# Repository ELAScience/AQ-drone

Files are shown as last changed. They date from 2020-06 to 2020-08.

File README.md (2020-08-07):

# AQ-drone

The AQ-drone project is an open source air quality measuring system utilizing drone technology to conduct air quality metrics. This project is inspired by the [JPL Open Source Rover Project](https://github.com/nasa-jpl/open-source-rover).

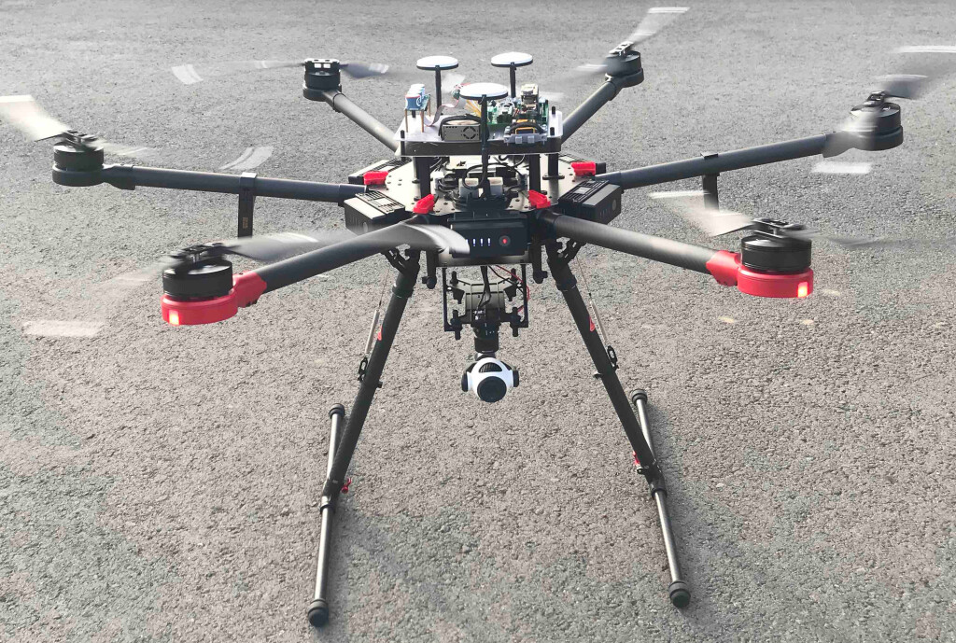
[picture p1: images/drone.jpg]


The goals of this project are two-fold:

1. To develop a pedagogical curriculum from which students can apply engineering and science skills to a real problem

2. To aggregate data from a distributed network of air quality sensors with the ultimate goal of understanding and improving environment impact of pollution on the community

## About AQ-drone

According to the EPA, air quality differs from region to region due to geographic location, proximity to pollution sources, and weather. Public health and environmental justice issues affect vulnerable communities, such as East Los Angeles, due to their proximity to freeways and interchanges, rail yards, industrial complexes and population density. Poor air quality is associated with detrimental effects on health and an increase in mortality (Dockery, et al., 1993). Establishing a cost effective and sustainable community driven air quality program is not only beneficial but necessary.

As community air quality investigators, we need to educate various stakeholders in the community about the air they experience in their surroundings. These units of concern are the residents, municipalities, elected officials, industrial/commercial businesses.

## Pedagogical Value

A key component of successful STEM instruction involves the application of concepts learned to real-world problems. Not only does this increase the retention of information and scientific inquiry, but, in the process, can lead to discoveries and contributions, thereby expanding the knowledge base as well as increasing the probability of pursuing a STEM-related career.

## Scientific Data

To test ambient air quality and pollution levels using aerial data collection rather than stationary, ground-level measuring locations.
The data collection should include metrics on carbon monoxide, ozone, nitrogen oxide, volatile organic compounds, particulate matter, hydrogen sulfide, methane and airborne lead.

## Equipment

The DJI Matrice 600 Pro Hexacopter drone is determined to be the most appropriate vehicle for carrying out this mission. Additionally, we will use on commercially available sensors for data collection. The sensors used and needed hardware can be found in the [hardware section](hardware/README.md). Post flight data analysis will be accomplished using open source software, and for campaign planning, we rely on Google Earth.

## Software

The software used can be found in the `software` directory. Documentation and instructions can be found in the [software guide](software/README.md).

## Project Team

### Principal Investigator

John J. Tran

### Development Team

Kevin Benavente, Steven Conaway, Michael Murray, and Jacqueline Curiel.

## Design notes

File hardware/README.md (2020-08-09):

# Hardware Guide

This project makes use of several off-the-shelf parts, however, it requires a few that are custom-made via PCB fabrication and 3D Printing.

## Parts List

| Name | Quantity | Cost (per unit, if applicable) | Supplier | Notes |
| --- | --- | --- | --- | --- |
| Custom Made PCB | 1 | \$0.40 | | We used JLCPCB to manufacture 5 copies for \$2.00 + shipping |
| PCB Base Plate | 1 | \$20.00 | | Used to secure the PCB and sensors to the drone's mounting kit. We used our own printer but makexyz.com seems to be the most cost-efficient. |
| Stacking Headers for Feather - 12-pin and 16-pin female headers | 3 | \$1.25 | Adafruit | Used to attach the FeatherWings to the Feather and the Feather to the PCB |
| Adafruit Feather M4 Express - Featuring ATSAMD51 - ATSAMD51 Cortex M4 | 1 | \$22.95 | Adafruit | |
| Adalogger FeatherWing - RTC + SD Add-on For All Feather Boards | 1 | \$8.95 | Adafruit | |
| Adafruit Ultimate GPS FeatherWing | 1 | \$39.95 | Adafruit | |
| GPS Antenna - External Active Antenna - 3-5V 28dB 5 Meter SMA | 1 | \$14.95 | Adafruit | |
| SMA to uFL/u.FL/IPX/IPEX RF Adapter Cable | 1 | \$3.95 | Adafruit | |
| CR1220 12mm Diameter - 3V Lithium Coin Cell Battery - CR1220 | 1 | \$0.95 | Adafruit | Backup battery for the GPS |
| ADS1115 16-Bit ADC - 4 Channel with Programmable Gain Amplifier | 2 | \$14.95 | Adafruit | |
| Adafruit BMP388 - Precision Barometric Pressure and Altimeter | 1 | \$9.95 | Adafruit | |
| Adafruit Sensirion SHT31-D - Temperature & Humidity Sensor | 1 | \$13.95 | Adafruit | |
| PM2.5 Air Quality Sensor and Breadboard Adapter Kit - PMS5003 | 1 | \$39.95 | Adafruit | |
| Arduino Nano | 1 | \$9.00 | Amazon | Used to interface with the PMS5003 |
| 3.3V, 3.6A Step-Down Voltage Regulator D36V28F3 | 1 | \$11.95 | Pololu | |
| 5V, 3.2A Step-Down Voltage Regulator D36V28F5 | 1 | \$11.95 | Pololu | |
| AlphaSense 4-Way AFE with CO, O3, NO, and H2S | 1 | \$379.00 | AlphaSense | |
| DJI Matrice 600 Pro | 1 | \$5699.00 | DJI | |
| DJI Matrice 600 Series Zenmuse X3/X5/XT/Z3 Series Gimbal Mounting Bracket | 1 | \$200.00 | DJI | |
| DJI Zenmuse X3 | 1 | - | DJI | At the time of making this list, pricing information for this was unavailable. |
| DJI Matrice 600 Upper Expansion Bay Kit | 1 | - | DJI | At the time of making this list, pricing information for this was unavailable. |
| - | - | - | - | - |
| **Total** | | **\$6511.5** | | |

## Assembly Instructions

1. Acquire all needed parts
2. Solder headers:
    1. Stacking Headers onto the Feather and two FeatherWings
    2. Male headers on the ADCs, Adafruit sensors, Pololu voltage Regulators, and Arduino Nano (if the one purchased doesn't include one)
    3. Solder female headers into the needed slots on the main PCB.
        1. Feather
        2. Arduino Nano
        3. PMS5003 connection
3. Solder the sensors into their assigned space on the main PCB. (Please see images for locations)
4. Mount the PCB, PMS5003, and AlphaSense sensors to the PCB Base Plate.
5. Attach PCB Base Plate to the `DJI Matrice 600 Upper Expansion Bay Kit`.

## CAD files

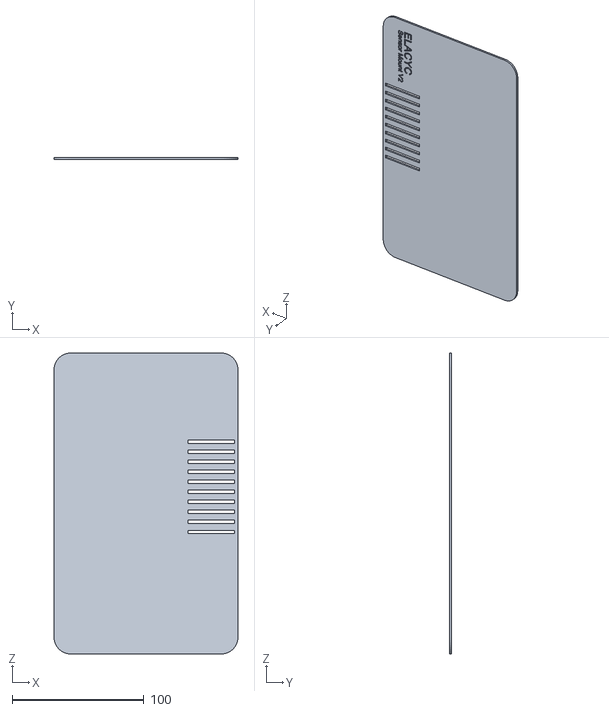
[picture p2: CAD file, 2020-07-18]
hardware/on-drone/3D-print-part-files/Sensor-Mount-V2-final.stl
139.7 x 1.59 x 228.6

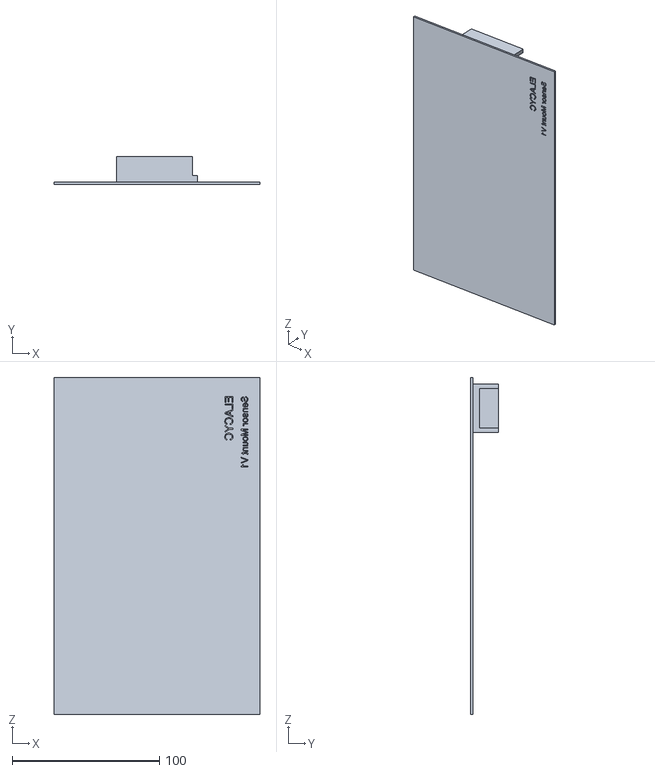
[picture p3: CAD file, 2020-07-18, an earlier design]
hardware/on-drone/3D-print-part-files/Sensor-Mount-V1-final.stl
139.7 x 19.1 x 228.6

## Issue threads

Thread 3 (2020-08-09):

Missing Prices for Parts List Items

SConaway, 2020-08-09:
These items are missing prices in the [parts list](https://github.com/ELAScience/AQ-drone/blob/master/hardware/README.md#parts-list):
* [DJI Zenmuse X3](https://store.dji.com/product/zenmuse-x3-gimbal-camera)
* [DJI Matrice 600 Upper Expansion Bay Kit](https://store.dji.com/product/matrice-600-upper-expansion-bay-kit)

They were listed as `Not available in your country/region` on DJI's web store, which is odd, as that's where we purchased them originally.

johnjtran, 2020-08-09:
Well, maybe we can just list them for now?

SConaway, 2020-08-09:
Ok. Will do.

Closed 2020-08-09.

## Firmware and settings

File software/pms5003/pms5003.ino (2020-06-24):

// On Leonardo / Micro or others with hardware serial, use those!
// Make sure to adjust your hardware configuration to match.
// uncomment the following line:
// #define pmsSerial Serial1

// For UNO and others without hardware serial, we must use software serial...
// pin #2 is IN from sensor (TX pin on sensor), leave pin #3 disconnected
// comment these two lines if using hardware serial
#include <SoftwareSerial.h>
SoftwareSerial pmsSerial(2, 3);

struct pms5003data {
    uint16_t framelen;
    uint16_t pm10_standard, pm25_standard, pm100_standard;
    uint16_t pm10_env, pm25_env, pm100_env;
    uint16_t particles_03um, particles_05um, particles_10um, particles_25um, particles_50um, particles_100um;
    uint16_t unused;
    uint16_t checksum;
};

struct pms5003data data;

bool new_data = false;

void setup() {
    // our output
    Serial.begin(115200);

    // sensor baud rate is 9600
    pmsSerial.begin(9600);
}

void loop() {
    readPMSdata(&pmsSerial);
    if (digitalRead(4)) {
        String ret = String(new_data) + "," + String(data.pm10_standard) + "," + String(data.pm25_standard) + "," + String(data.pm100_standard) + "," + String(data.pm10_env) + "," + String(data.pm25_env) + "," + String(data.pm100_env) + "," + String(data.particles_03um) + "," + String(data.particles_05um) + "," + String(data.particles_10um) + "," + String(data.particles_25um) + "," + String(data.particles_100um) + ",\n";
        Serial.print(ret);
        new_data = false;
        while (digitalRead(4))
            ;
    }
}

boolean readPMSdata(Stream *s) {
    if (!s->available()) {
        return false;
    }

    // Read a byte at a time until we get to the special '0x42' start-byte
    if (s->peek() != 0x42) {
        s->read();
        return false;
    }

    // Now read all 32 bytes
    if (s->available() < 32) {
        return false;
    }

    uint8_t buffer[32];
    uint16_t sum = 0;
    s->readBytes(buffer, 32);

    // get checksum ready
    for (uint8_t i = 0; i < 30; i++) {
        sum += buffer[i];
    }

    // The data comes in endian'd, this solves it so it works on all platforms
    uint16_t buffer_u16[15];
    for (uint8_t i = 0; i < 15; i++) {
        buffer_u16[i] = buffer[2 + i * 2 + 1];
        buffer_u16[i] += (buffer[2 + i * 2] << 8);
    }

    // put it into a nice struct :)
    memcpy((void *)&data, (void *)buffer_u16, 30);

    if (sum != data.checksum) {
        Serial.println("Checksum failure");
        return false;
    }

    new_data = true;
    // success!
    return true;
}

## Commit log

2020-06-24 Add sketch for the arduino nano connected to the PMS5003
2020-06-24 Add python code for sensors
2020-07-07 Add PCB
    [circuit.fzz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]
2020-07-18 Add 3D print part files
    [Sensor-Mount-V1-final.stl, Sensor-Mount-V2-final.stl]
2020-07-28 First cut at updating README
2020-08-08 Rename PCB files to make sense
    [circuit_contour.gm1, circuit_copperBottom.gbl, circuit_copperTop.gtl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]
2020-08-08 Add preliminary assembly instructions
2020-08-08 Add installation instructions for Arduino Nano
